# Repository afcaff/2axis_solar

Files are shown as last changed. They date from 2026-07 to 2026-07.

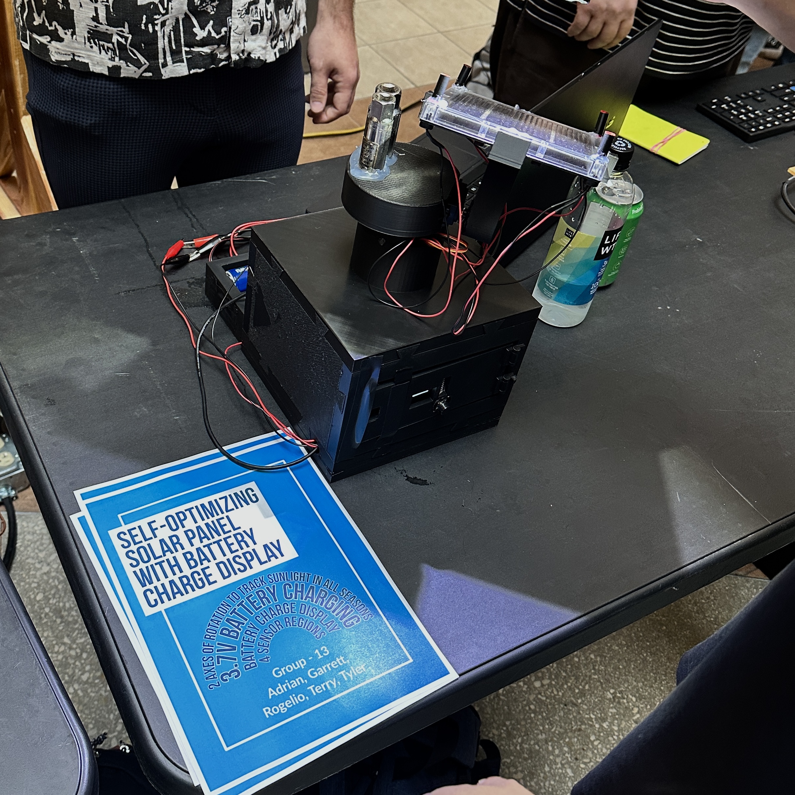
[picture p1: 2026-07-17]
table.jpeg

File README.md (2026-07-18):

# Dual Axis Solar Tracker
**🏆 Third Place in Micro Computers competition!**

A two-axis (pan/tilt) solar tracking system built on a PIC16F1829, developed as a team final project for Micro Computer course. The tracker automatically orients a solar panel toward the brightest available light source using quadrant photoresistor sensing and closes the loop through hardware PWM servo control, while charging a LiPo battery from the panel.

## Overview
 
- **MCU:** Microchip PIC16F1829
- **IDE:** MPLAB X IDE with the XC8 compiler
- **Sensing:** Four photoresistors in a quadrant layout 
- **Actuation:** Two MG995 servos, driven by hardware PWM
- **Display:** SSD1306 OLED showing live pan/tilt angle and system status
- **Power:** Panel charged LiPo battery with a shift-register LED bar gauge and push-button readout
- **Mechanical:** Custom 3D printed  gimbal assembly designed in Fusion 360

solar

solar1

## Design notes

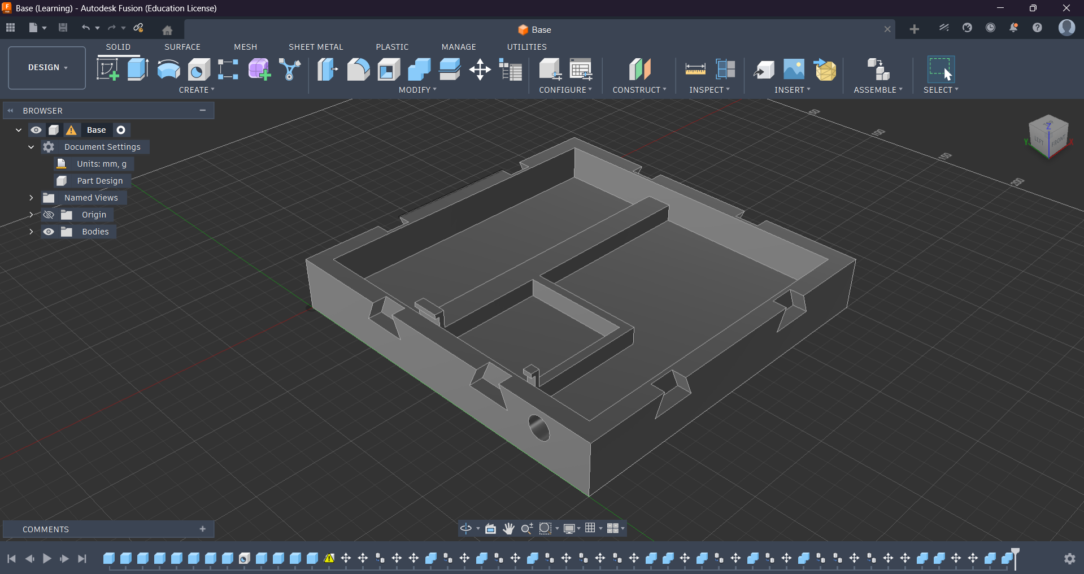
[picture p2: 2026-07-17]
cad/TerryH/Base v1.png

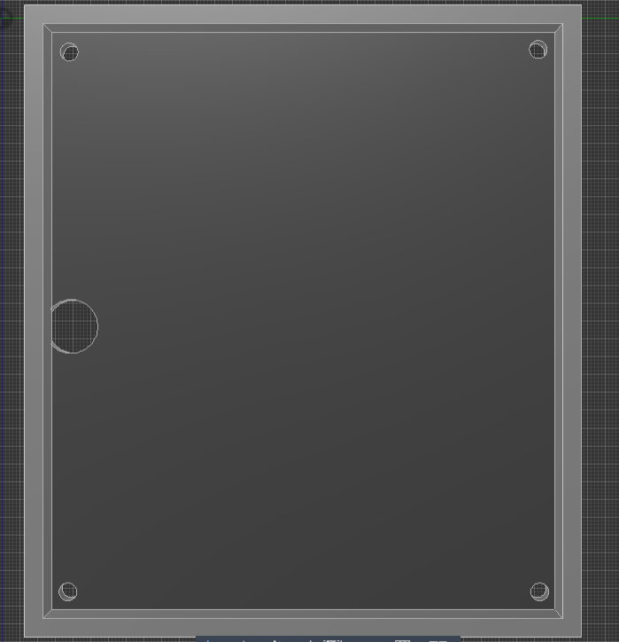
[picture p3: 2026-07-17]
cad/TerryH/Panel Holder Top View.png

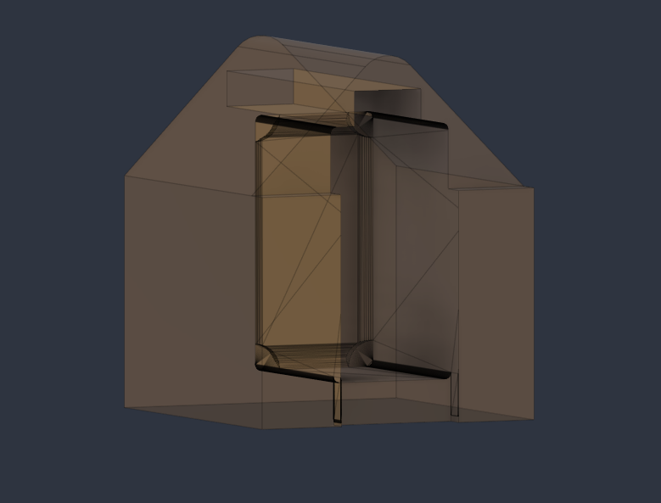
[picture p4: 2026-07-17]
cad/adrian/servomount.png

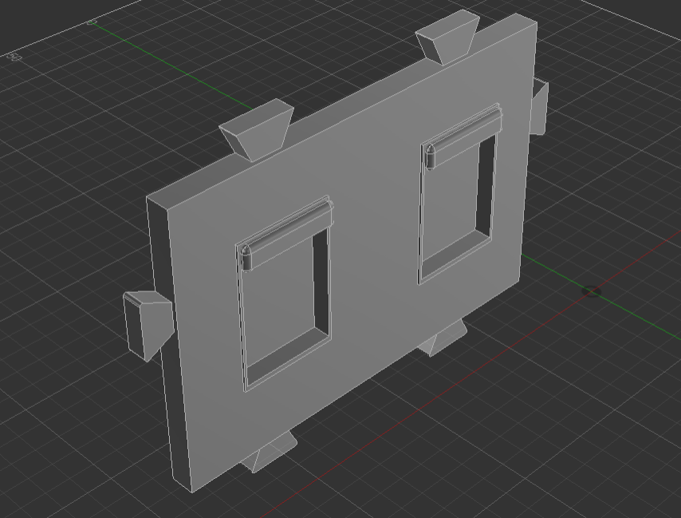
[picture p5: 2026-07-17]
cad/TerryH/Left Wall.png

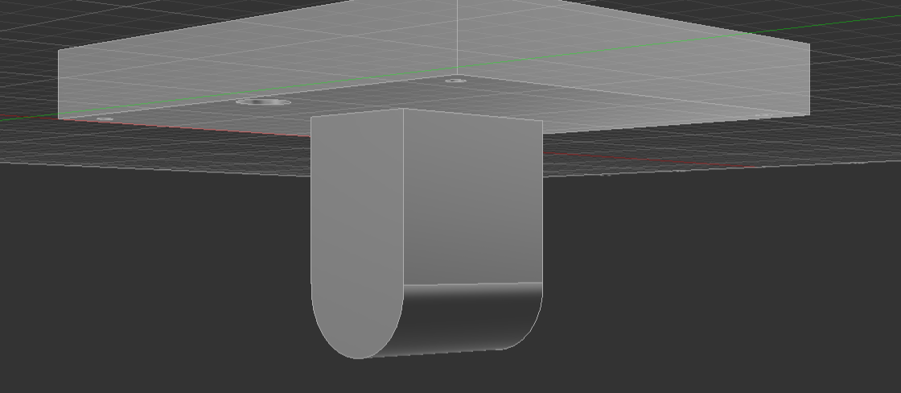
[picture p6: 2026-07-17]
cad/TerryH/Panel Holder Bottom Left View.png

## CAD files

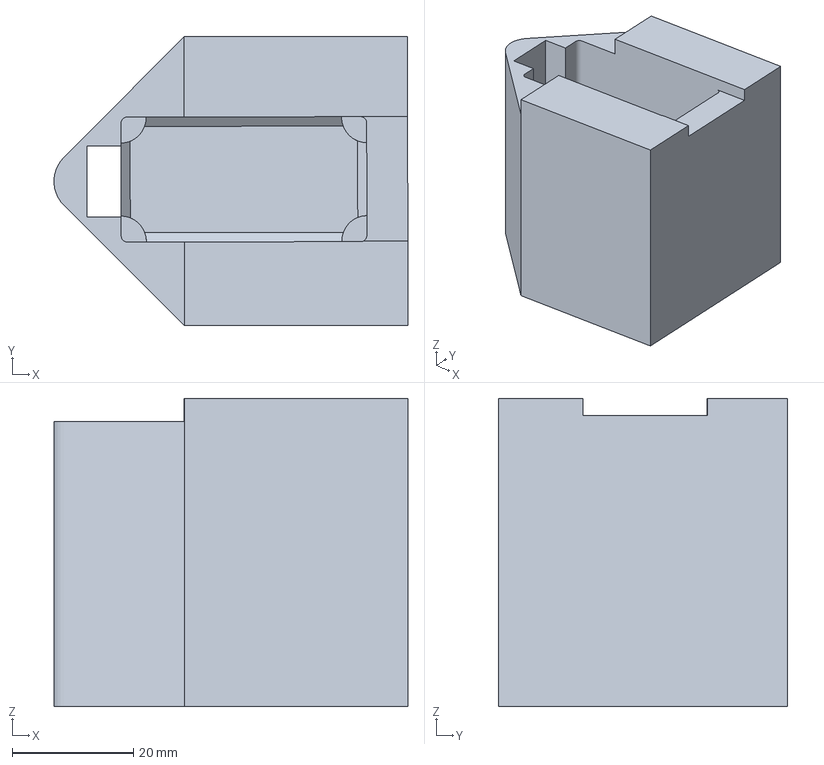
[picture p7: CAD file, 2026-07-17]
cad/adrian/servomount.3mf
58.4 x 47.7 x 50.8 mm

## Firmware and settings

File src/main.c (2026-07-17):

/*
 * File:   main.c
 * Author: Terry
 *
 */

//Config bits (PIC16F1829) 
#pragma config FOSC  = INTOSC   // internal osc, no ext crystal needed
#pragma config WDTE  = OFF      // watchdog off (turn on for final build)
#pragma config PWRTE = ON       // power-up timer on
#pragma config MCLRE = ON       // MCLR pin enabled
#pragma config CP    = OFF      // code protection off
#pragma config CPD   = OFF      // data protection off
#pragma config BOREN = ON       // brown-out reset on
#pragma config CLKOUTEN = OFF   // CLKOUT disabled
#pragma config IESO  = OFF
#pragma config FCMEN = OFF
//================ CONFIGURATION - LED =================//
#pragma config WRT = OFF, PLLEN = OFF, STVREN = ON
#pragma config BORV = LO, LVP = ON
//================ CONFIGURATION - PWM =================//

#include <xc.h>
#include <stdint.h>
#include "angle_cmd.h"
#include "adc_v2.h"  // gives you light_reading_t, ADC_Init, adc_scan_average, adc_send_result
#include "led.h"    
#include "servo.h"

#include "oled.h"
#define _XTAL_FREQ 2000000   // 2 MHz

//================ PIN DEFINITIONS - PWM ================//
#define LDR_TL 0 // RA0/AN0
#define LDR_TR 1 // RA1/AN1
#define LDR_BL 2 // RA2/AN2
#define LDR_BR 3 // RA4/AN3 (RA3 has no Analog select bit)

void main(void) {
    OSCCON = 0x68;
    
    // pin directions ? master mask
    TRISAbits.TRISA0 = 1;   // RA0 analog input PR1
    TRISAbits.TRISA1 = 1;   // RA1 analog input PR2
    TRISAbits.TRISA2 = 1;   // RA2 analog input PR3
    TRISAbits.TRISA4 = 1;   // RA4 analog input PR4
    TRISAbits.TRISA5 = 1;   // RA5 analog input Voltage Divider
    TRISCbits.TRISC0 = 0;   // RC0 output Batt
    TRISCbits.TRISC1 = 0;   // RC1 output Batt
    TRISCbits.TRISC2 = 0;   // RC2 output Batt
    TRISCbits.TRISC5 = 0;   // RC5 output pan servo PWM
    TRISCbits.TRISC3 = 0;   // RC3 output tilt servo PWM
    TRISBbits.TRISB4 = 1;   // RB4 analog input - OLED IC2
    TRISBbits.TRISB5 = 1;   // RB5 analog input - battery voltage
    TRISBbits.TRISB6 = 1;   // RB6 analog input - OLED IC2
    TRISBbits.TRISB7 = 1;   // RB7 input Batt pushbutton
    ANSELBbits.ANSB5 = 1;  // RB5 as analog input
    ANSELAbits.ANSA0 = 1;   // RA0 analog
    ANSELAbits.ANSA1 = 1;   // RA1 analog
    ANSELAbits.ANSA2 = 1;   // RA2 analog
    ANSELAbits.ANSA4 = 1;   // RA4 analog
    TRISCbits.TRISC7 = 1;
    ANSELCbits.ANSC7 = 1;
    
    //define PR structure
    light_reading_t reading = {0};
    angle_cmd_t cmd = {0};
    //Initialize all components
    ADC_Init();
    PWM_Init();
    Battery_Init();
    goHome();
    OLED_Init();
    OLED_Splash();
    
    //run and iterate loop
    int i = 0;
    while(1) {
        //read PR values
        adc_scan_average(&reading);
        //send to PWM
        adc_send_result(&reading, &cmd);
        //Move servos
        servo_update(cmd.lux_max, cmd.pan_error, cmd.tilt_error, &cmd);
        //Update OLED angle display
        if(i==25)
            {
            OLED_Update(cmd.pan_angle, cmd.tilt_angle);
            i=0;
            }
            i++;
        //Polls button to see if pushed
        Battery_Check();
    }
}

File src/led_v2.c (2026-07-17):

/*
 * File:   LED_test.c
 * Author: Tyler Jewell
 *
 * Description:
 * Battery level indicator using ADC + 10-segment LED bar
 * via cascaded 74HC595 shift registers
 *
 * Features:
 * - 2 MHz system clock (team standard)
 * - ADC averaging (reduces noise)
 * - Stable LED output (no flicker)
 * - Calibrated scaling for your hardware
 */
//================ BATTERY MODULE =================//
// Uses:
// RA1  -> ADC (battery voltage)
// RB7  -> Push button input
// RC0  -> DATA (74HC595)
// RC1  -> CLOCK
// RC2  -> LATCH

#include <xc.h>
#include <stdint.h>

#define _XTAL_FREQ 2000000

// CONFIG
#pragma config FOSC = INTOSC, WDTE = OFF, PWRTE = OFF, MCLRE = ON
#pragma config CP = OFF, CPD = OFF, BOREN = ON, CLKOUTEN = OFF
#pragma config IESO = OFF, FCMEN = OFF
#pragma config WRT = OFF, PLLEN = OFF, STVREN = ON
#pragma config BORV = LO, LVP = ON

// PINS
#define DATA    LATCbits.LATC0
#define SRCLK   LATCbits.LATC1
#define RCLK    LATCbits.LATC2
#define BUTTON  PORTBbits.RB7

// READ ADC
uint16_t readADC(void)
{
    ADCON0bits.CHS = 0b00001;  // AN1

    // Dummy read (flush sample capacitor)
    __delay_us(20);
    ADCON0bits.GO = 1;
    while (ADCON0bits.GO);

    // Real read (longer settle time)
    __delay_us(100);
    ADCON0bits.GO = 1;
    while (ADCON0bits.GO);

    return ((ADRESH << 8) | ADRESL);
}

// SHIFT REGISTER
void shiftOut16(uint16_t data)
{
    for (uint8_t i = 0; i < 16; i++)
    {
        DATA = (data & 0x8000) ? 1 : 0;

        SRCLK = 1;
        __delay_us(5);
        SRCLK = 0;

        data <<= 1;
    }

    RCLK = 1;
    __delay_us(5);
    RCLK = 0;
}

// LED SCALING
uint16_t getBarPattern(uint16_t adcValue)
{
    // Slightly adjusted range
    if (adcValue < 180) adcValue = 180;
    if (adcValue > 300) adcValue = 300;

    uint8_t level = (adcValue - 180) * 10 / (300 - 180);

    if (level > 10) level = 10;

    uint16_t pattern = 0;

    for (uint8_t i = 0; i < level; i++)
        pattern |= (1 << i);

    return pattern;
}

// MAIN
void main(void)
{
    while (1)
    {
        if (BUTTON == 0)
        {
            __delay_ms(50);

            if (BUTTON == 0)
            {
                uint16_t adcValue = readADC();
                uint16_t pattern = getBarPattern(adcValue);
                shiftOut16(pattern);
            }
        }
        else
        {
            shiftOut16(0x0000);
        }

        __delay_ms(100);
    }
}

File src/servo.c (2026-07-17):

// Name: Rogelio Maltos
// Date: 04/09/2026
// Modified by: Terry Herres
// Date: 04/20/2026
// Solar Panel Servos
// ---------------------------------------------------------------
// Configuration bits
// ---------------------------------------------------------------

#include <xc.h>
#include "servo.h"
#include "angle_cmd.h"

#define _XTAL_FREQ 2000000


// Servo positioning
static int x_posi = home_x; // creates reference points so we may code an easier while loop
static int y_posi = home_y; //
static int atHome = 0; // prevents work through the night
// PWM Setup
// DC value = pulse_us / 32
// upper 8 bits in CCPRxL
// Lower 2 bits in DCxB of CCPxCON
// PWM set up for x_axis servo
static void setPWM1(int pulse_us){
    int dc_value = pulse_us / 32;
    CCPR1L = (uint8_t)(dc_value >> 2); // shifts upper 8 bits right
    CCP1CONbits.DC1B = dc_value & 0x03; // equivalent to (CCP1CON & 0b11001111) |
}
// PWM set up for y_axis servo
static void setPWM2(int pulse_us){
    int dc_value = pulse_us / 32;
    CCPR2L = (uint8_t)(dc_value >> 2);
    CCP2CONbits.DC2B = dc_value & 0x03;
}
/* Clamp to keep solar panels from going trying to go beyond physical limit, keeps from high
current, drawing heat, and striping gears*/
static int clamp(int val, int lo, int hi){
    if (val < lo) return lo;
    if (val > hi) return hi;
    return val;
}
/* Drives both servos to home position doing top servo first to keep from traversing in awkward
angles*/
void goHome(){
    y_posi = home_y;
    setPWM2(y_posi);

    __delay_ms(500);
    x_posi = home_x;
    setPWM1(x_posi);
    __delay_ms(500);
    atHome = 1;
}

void PWM_Init(void){
    
    // Load PRx register with PWM Period
    PR2 = PR2_value;
    /* Configure CCP module for PWM mode by loading CCPxCON register with appropriate
    values*/
    CCPTMRS = 0;
    CCP1CON = 0x0C;
    setPWM1(home_x);
    CCP2CON = 0x0C;
    setPWM2(home_y);
    // Configure and start timer2/4/6
    T2CONbits.T2CKPS = 0b11;
    T2CONbits.TMR2ON = 1; 
    
}

// main
void servo_update(int16_t lux_max, int16_t x_err, int16_t y_err, angle_cmd_t *cmd){ //Need to make sure these are all ints, and also they output from pr in the right order.
//night detection
// all four ldrs below night thresh go home
    
    /*if (lux_max < Night_Threshold) // all sensors dark if max is below threshold 
    {
        if (!atHome) goHome();
        cmd->pan_angle  = 60;  
        cmd->tilt_angle = 60;
        __delay_ms(500);
        return;
    }*/
    // daytime clear home flag
    atHome = 0;

    // Dead Band and Step
    if (x_err > Dead_Band) x_posi = clamp(x_posi + step_size_x, Neg_x, Pos_x);
    if (x_err < -Dead_Band) x_posi = clamp(x_posi - step_size_x, Neg_x, Pos_x);
    if (y_err > Dead_Band) y_posi = clamp(y_posi + step_size_y, Neg_y, Pos_y);
    if (y_err < -Dead_Band) y_posi = clamp(y_posi - step_size_y, Neg_y, Pos_y);
    cmd->pan_angle  = (uint8_t)((x_posi - Neg_x) * 120 / (Pos_x - Neg_x));
    cmd->tilt_angle = (uint8_t)((y_posi - Neg_y) * 120 / (Pos_y - Neg_y));
    
    // update servos simultaneously
    
    
    setPWM1(x_posi);
    setPWM2(y_posi);
    __delay_ms(100);
}

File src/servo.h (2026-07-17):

#ifndef SERVO_H
#define SERVO_H

#include <xc.h>
#include <stdint.h>

#define PR2_value    155
#define Neg_x        550
#define Pos_x        2550
#define home_x       1550
#define step_size_x  32
#define Neg_y        1050
#define Pos_y        2050
#define home_y       1550
#define step_size_y  32

//These two values may be the most likely to need modifications
#define Dead_Band        150
#define Night_Threshold  50


#include "angle_cmd.h"
void PWM_Init(void);
void goHome(void);
void servo_update(int16_t, int16_t, int16_t, angle_cmd_t *cmd);

#endif
